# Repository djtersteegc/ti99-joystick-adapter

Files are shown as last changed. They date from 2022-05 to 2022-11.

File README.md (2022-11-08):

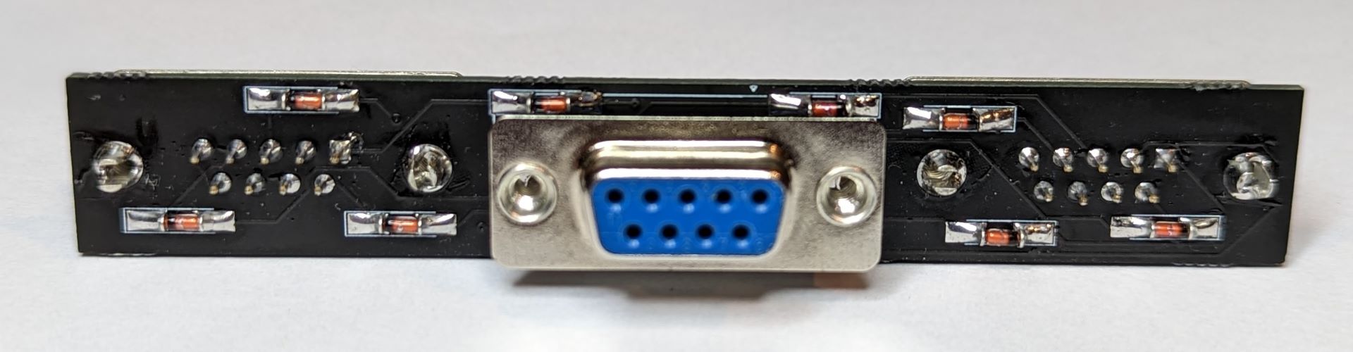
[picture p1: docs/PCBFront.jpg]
PCBFront


TI-99/4A joystick adapter allowing for the use of two standard Atari style DB9 joysticks.  BOM is super simple, I used these DB9's from AliExpress (similar to a TE [2301826-2](https://www.te.com/usa-en/product-2301826-2.html) and [2301838-2](https://www.te.com/usa-en/product-2301838-2.html) )

https://www.aliexpress.us/item/2255799921187046.html

and some LL4148 diodes in a MiniMELF form factor

https://www.aliexpress.us/item/3256802562651339.html

The top of the 4-40 lugs simply unscew from the DB9 sockets leaving the bottom part to securly mount to the PCB.

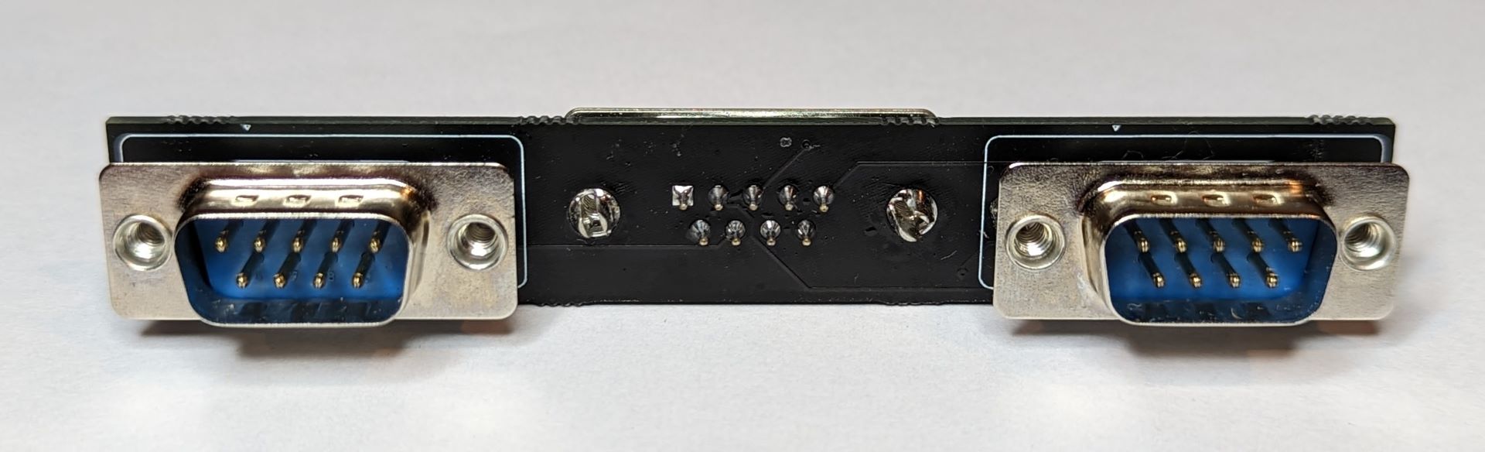
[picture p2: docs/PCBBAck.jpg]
PCBBack


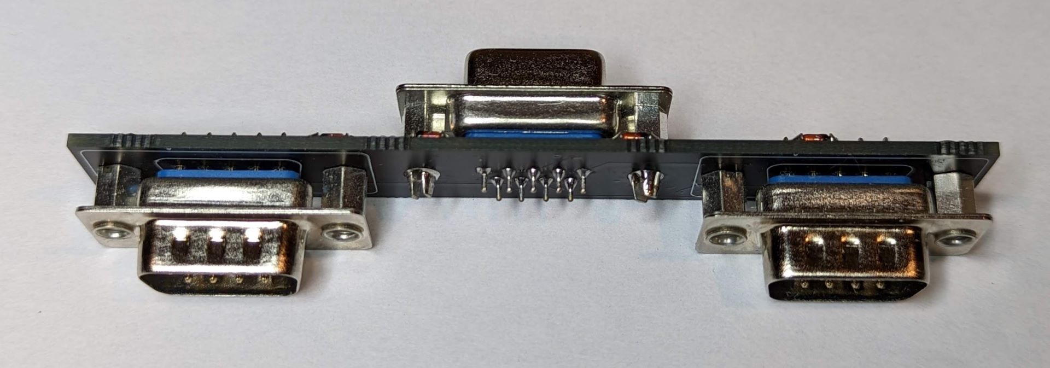
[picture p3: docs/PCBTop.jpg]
PCBTop


There is a snapfit 3D printable case in the **enclosure** directory.  Prints fine without any sort of supports, clearances are 0.2mm which work well on my Ender 3 style printer when printed in standard PLA. I included the DesignSpark file and STEP export of the populated board if you would like to improve on it further.

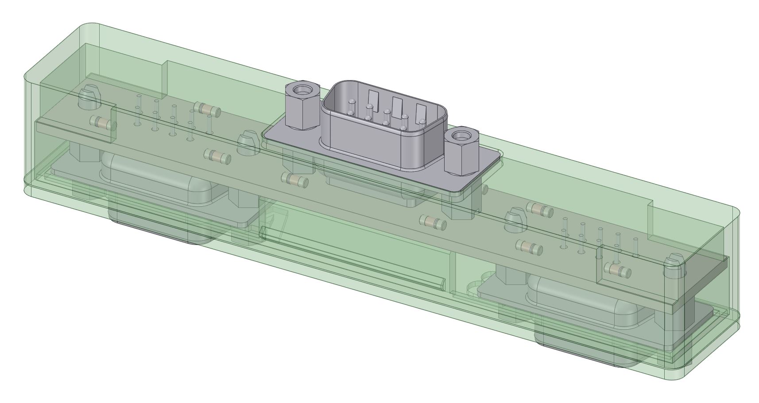
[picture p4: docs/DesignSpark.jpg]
DesignSpark


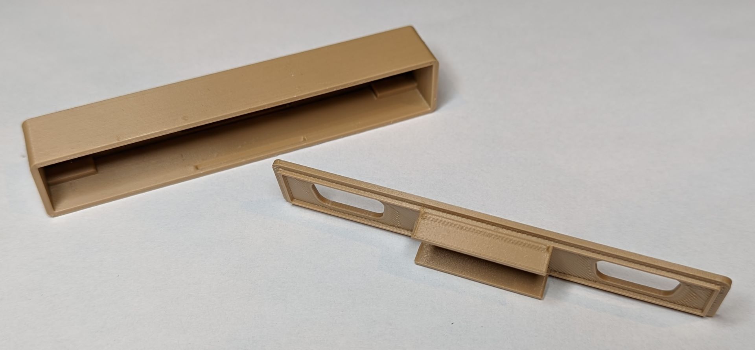
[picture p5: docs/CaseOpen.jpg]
CaseOpen


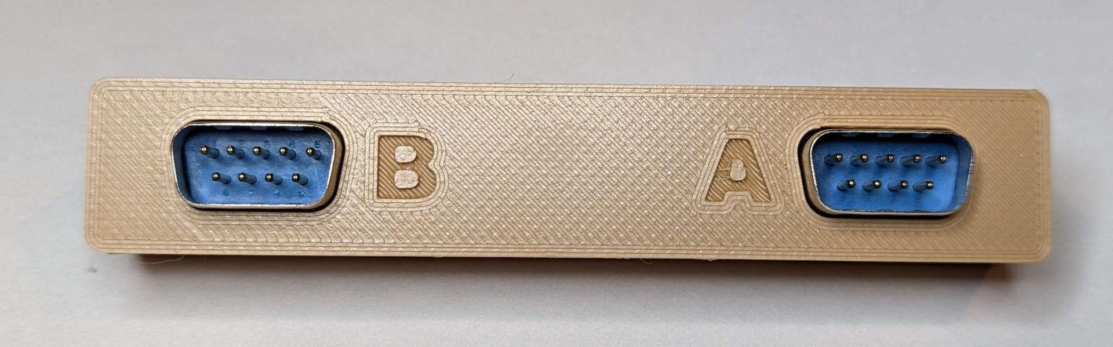
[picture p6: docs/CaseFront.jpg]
CaseFront


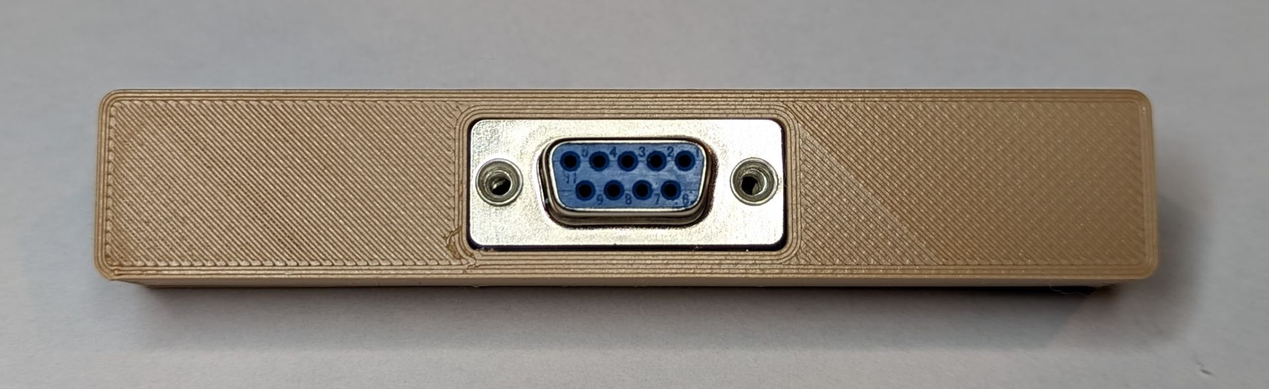
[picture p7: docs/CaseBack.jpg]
CaseBack


In the **gerbers** directory there is also a panelized version that will produce six boards on a standard 100x100mm PCB.  That was before JLCPCB started charging more for panelized design, so use at your your own (financial) risk these days.

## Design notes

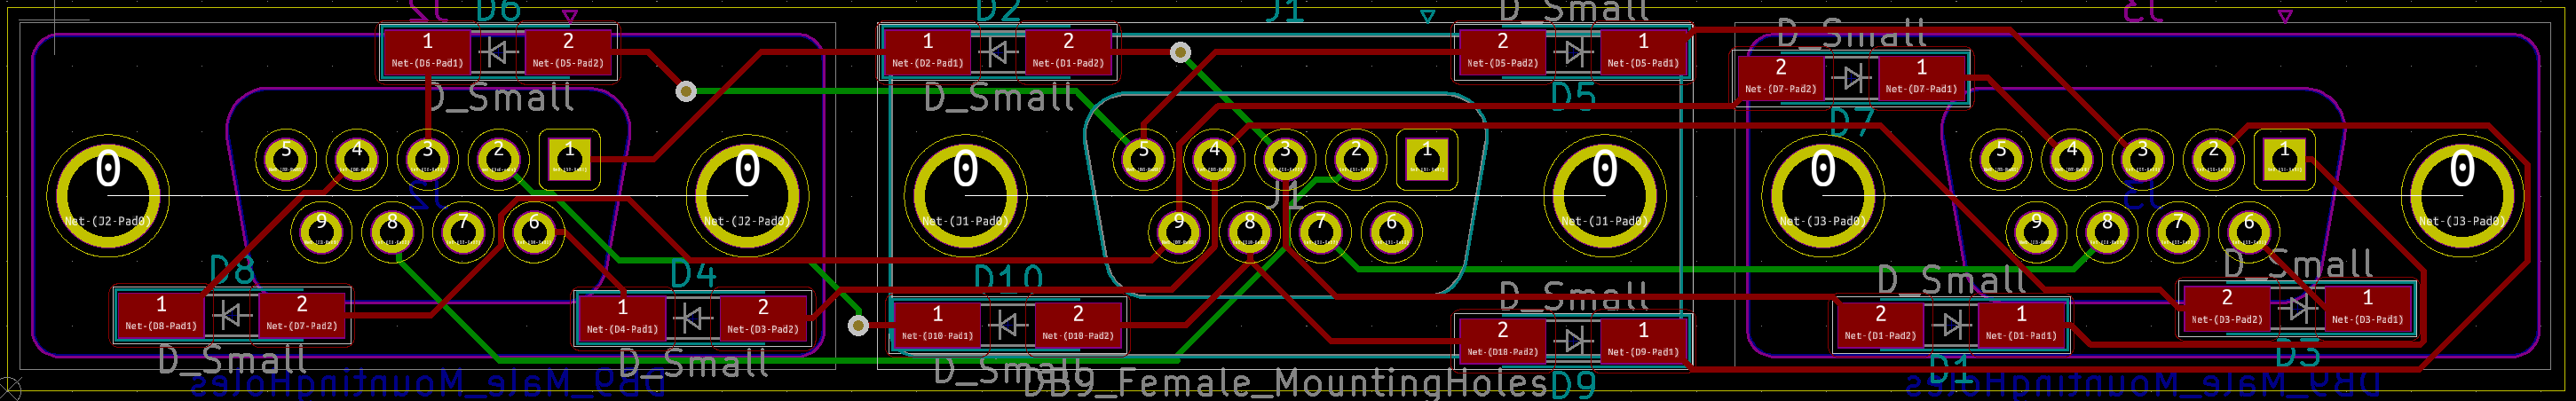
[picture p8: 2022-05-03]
pcb.png

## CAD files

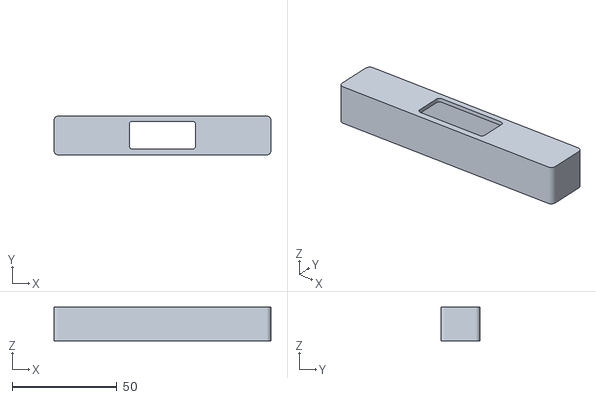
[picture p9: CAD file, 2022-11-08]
enclosure/basic/body.stl
103.6 x 18.6 x 16.1

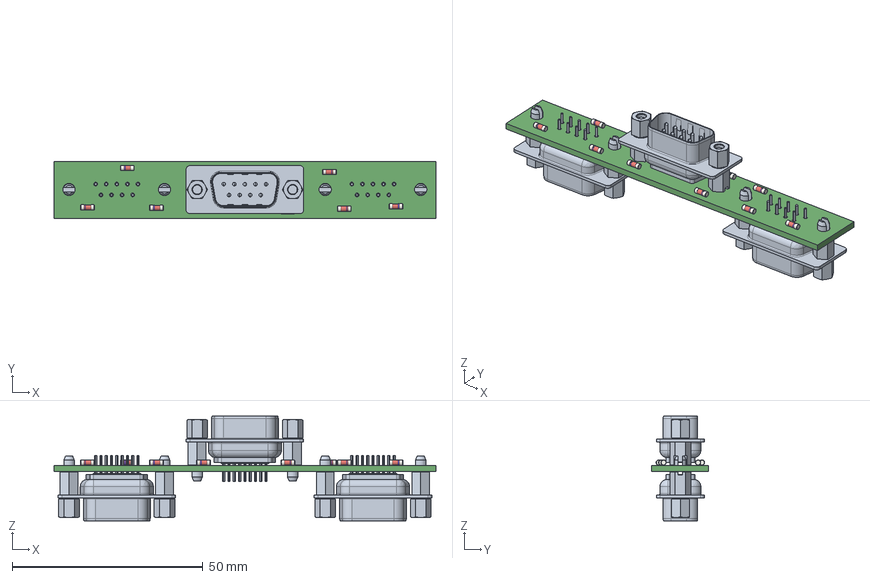
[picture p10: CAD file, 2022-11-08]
enclosure/ti99-joystick-adapter.step
100.0 x 15.0 x 27.4 mm

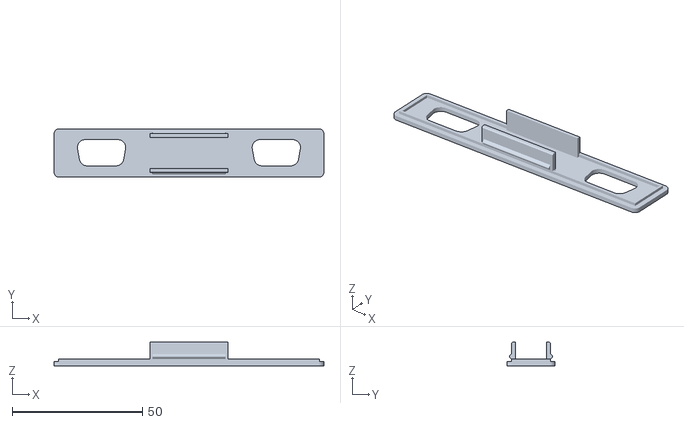
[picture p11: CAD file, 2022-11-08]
enclosure/basic/lid.stl
103.6 x 18.6 x 9.10

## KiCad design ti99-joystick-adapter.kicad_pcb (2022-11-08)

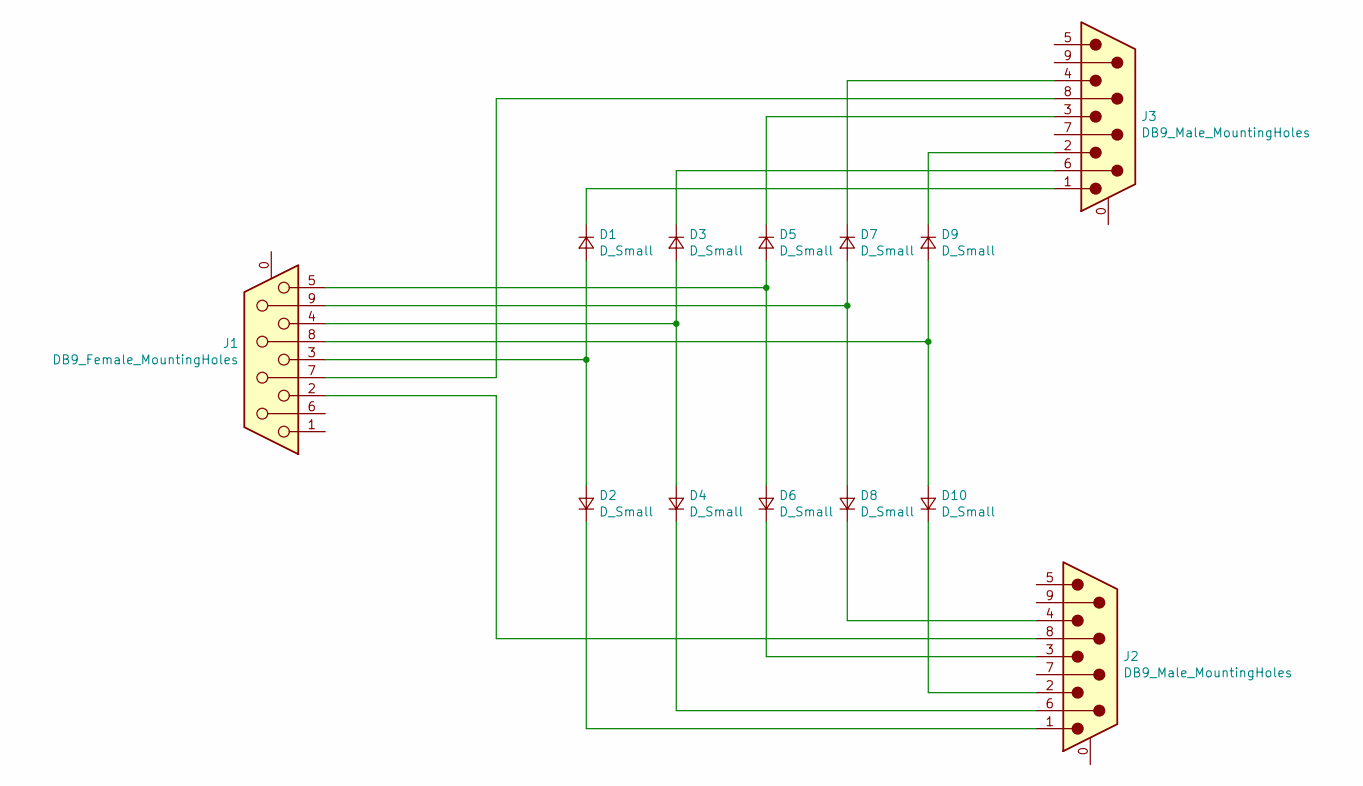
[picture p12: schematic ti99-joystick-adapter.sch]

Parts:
D1, D2, D3, D4, D5, D6, D7, D8, D9, D10: D_Small; D_MiniMELF_Handsoldering
J1: DB9_Female_MountingHoles; DSUB-9_Female_Vertical_P2.77x2.84mm_MountingHoles
J2, J3: DB9_Male_MountingHoles; DSUB-9_Male_Vertical_P2.77x2.84mm_MountingHoles

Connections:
unnamed: D1.1 (K), J3.1
unnamed: D1.2 (A), D2.2 (A), J1.3
unnamed: D2.1 (K), J2.1
unnamed: D3.1 (K), J3.6
unnamed: D3.2 (A), D4.2 (A), J1.4
unnamed: D4.1 (K), J2.6
unnamed: D5.1 (K), J3.3
unnamed: D5.2 (A), D6.2 (A), J1.5
unnamed: D6.1 (K), J2.3
unnamed: D7.1 (K), J3.4
unnamed: D7.2 (A), D8.2 (A), J1.9
unnamed: D8.1 (K), J2.4
unnamed: D9.1 (K), J3.2
unnamed: D10.1 (K), J2.2
unnamed: D9.2 (A), D10.2 (A), J1.8
unnamed: J1.2, J2.8
unnamed: J1.7, J3.8

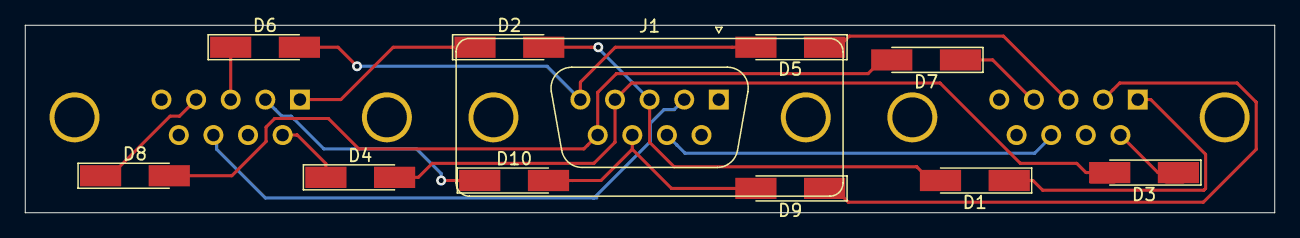
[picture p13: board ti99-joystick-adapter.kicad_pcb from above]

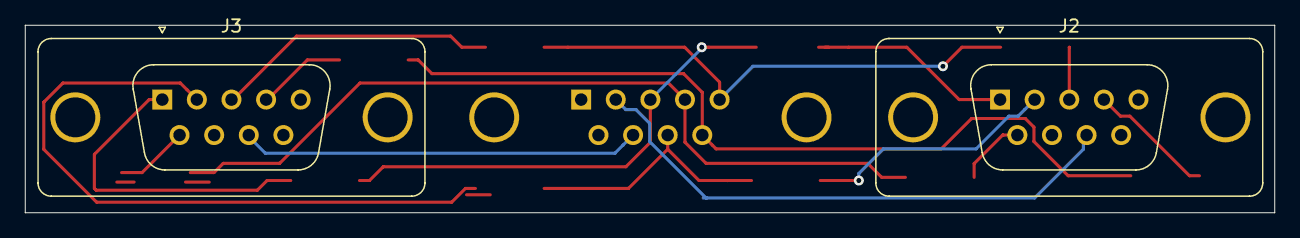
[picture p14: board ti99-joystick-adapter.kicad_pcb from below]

Board: 2 copper layers, 100.0 x 15.0 mm, 13 parts (2 on the bottom side), 17 nets.

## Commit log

2021-02-28 Initial version set to JCL
    [combined.GKO, combined.drl, combined.gbl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]
2022-11-08 Fixup 3D models
    [ti99-joystick-adapter.kicad_pcb]
2022-11-08 Add enclosure
    [body.stl, lid.stl, ti99-joystick-adapter.step]
